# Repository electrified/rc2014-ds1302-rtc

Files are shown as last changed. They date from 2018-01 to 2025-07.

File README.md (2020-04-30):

# DS1302 Real Time Clock for the RC2014 computer

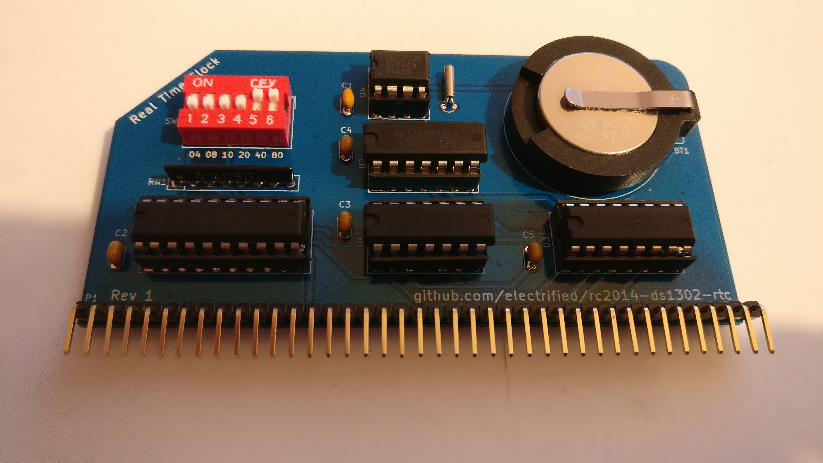
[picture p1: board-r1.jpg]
Picture of the board


## The board
RomWBW has code to support a DS1302 Real Time Clock, enabling files to be timestamped and other timekeeping operations. This board implements the clock in a standard way for the RC2014. 

The design is largely based on the clock implementation on the [RetroBrew Computers SBC V2](https://retrobrewcomputers.org/doku.php?id=boards:sbc:sbc_v2:start) and [Zeta SBC V2](http://www.malinov.com/Home/sergeys-projects/zeta-sbc-v2).

## What can you use this for?
Telling the time :)

## Getting started with RomWBW

Set ```DSRTCENABLE``` to true in the configuration and rebuild your ROM image.

On startup you will see the time shown.

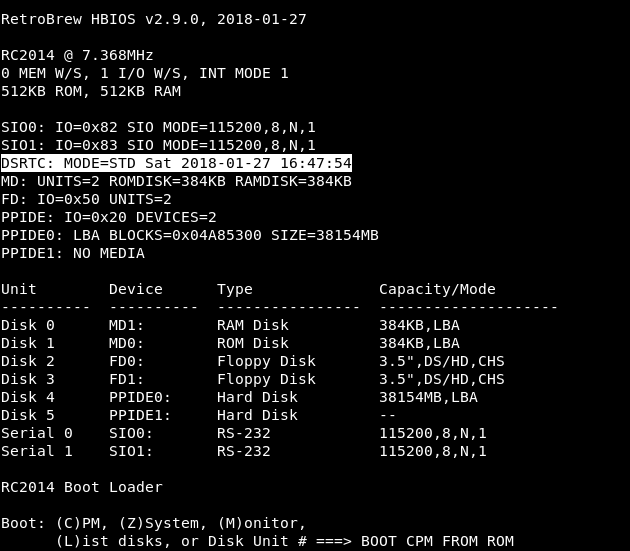
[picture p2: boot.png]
Boot


ZSystem has more complete support for time utilities than CP/M. After booting into ZSystem by pressing Z, Run ```ldds``` to load the resident time driver. ```td``` can then be used to set the time as well as view it.

In CP/M ```RTC.com``` can be used for querying and setting the clock but it is very basic.

## Jumpers
SW1 - Address configuration. For the default address of 0xC0, set switches 5 and 6 to on.

## Bill Of Materials

Reference| Value|Farnell part no|Rapid part no|Digi-key part no|
---------|------|---------------|-------------|----------------|
P1|1x39 right angled pin header|||732-5350-ND|
BT1|Keystone 106 20mm battery holder for CR2032|1650672||36-106-ND|
BT1|CR2032 battery|||P189-ND|
U1|CD74HCT688E COMPARATOR, SINGLE, PDIP-20|2407104||296-2131-5-ND|
U2|SN74HCT125N LOGIC, BUS BUFF TRI-ST QD, 14DIP|1739676||296-8386-5-ND|
U3|CD74HCT174E 74HCT CMOS, 74HCT174, DIP16, 5.5V|1105983||296-2100-5-ND|
U4|DS1302N+ RTC W/ RAM, 248B, D-D-M-Y, HH:MM:SS, DIP|2515367||DS1302N+-ND|
U5|SN74HCT32N IC, QUAD 2-INPUT OR, 74HCT32, DIP14|9591982||296-1615-5-ND|
C1-5|0.1uF MLCC capacitor|||BC2665CT-ND|
Y1|32.768 kHz crystal|9712887||535-9034-ND|
RN1|10k 8 Pin Commoned Resistor Network||63-0125|4608X-1-103LF-ND|
SW1|6 way DIL switch||80-0338|CT2066-ND|
U1|CONN IC DIP SOCKET 20POS TIN|||AE10015-ND|
U2|CONN IC DIP SOCKET 14POS TIN|||AE10012-ND|
U3|CONN IC DIP SOCKET 16POS TIN|||AE10013-ND|
U4|CONN IC DIP SOCKET 8POS TIN|||AE10011-ND|
U5|CONN IC DIP SOCKET 14POS TIN|||AE10012-ND|

## Construction tips
The footprint for the battery holder is designed for a Keystone 106, other battery holders should work if the pins are ~20.5mm apart, which seems to be fairly standard.

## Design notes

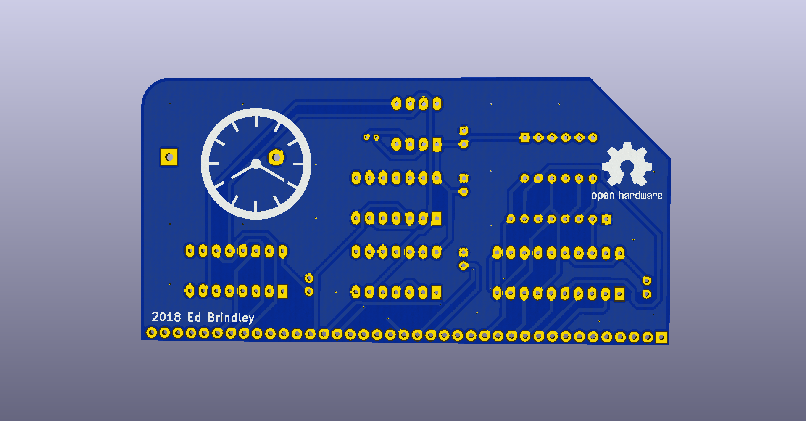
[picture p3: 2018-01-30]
rc2014-ds1302-rtc-back.png

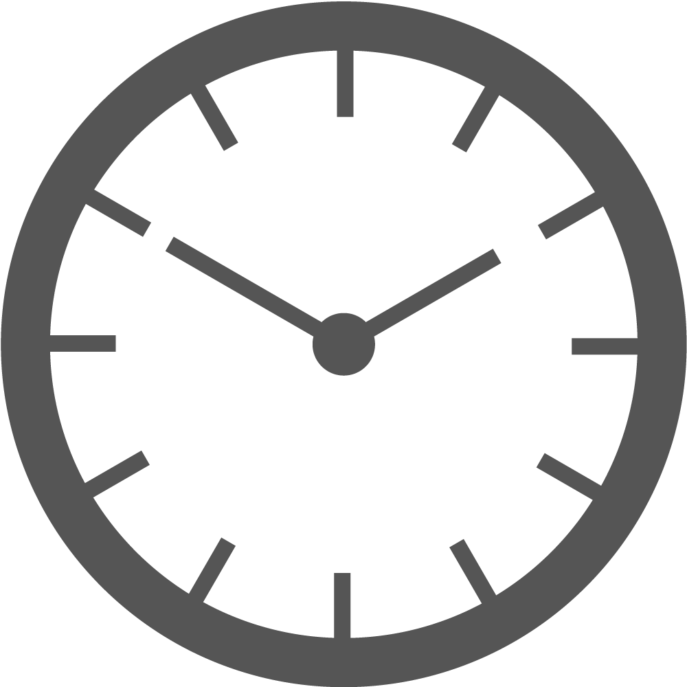
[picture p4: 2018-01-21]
clock.png

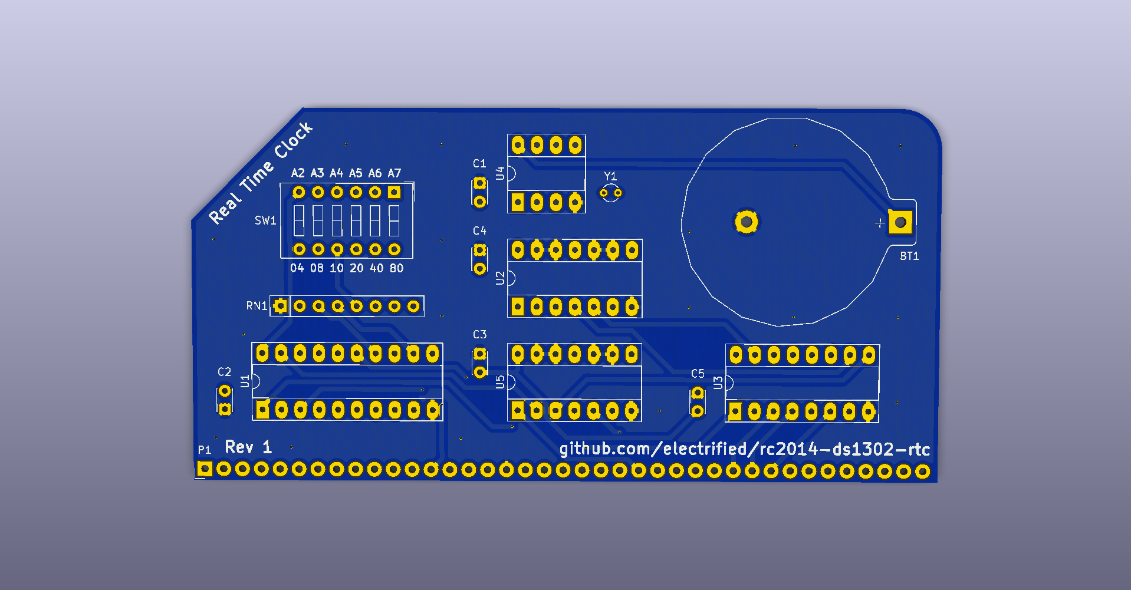
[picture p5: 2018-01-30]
rc2014-ds1302-rtc-front.png

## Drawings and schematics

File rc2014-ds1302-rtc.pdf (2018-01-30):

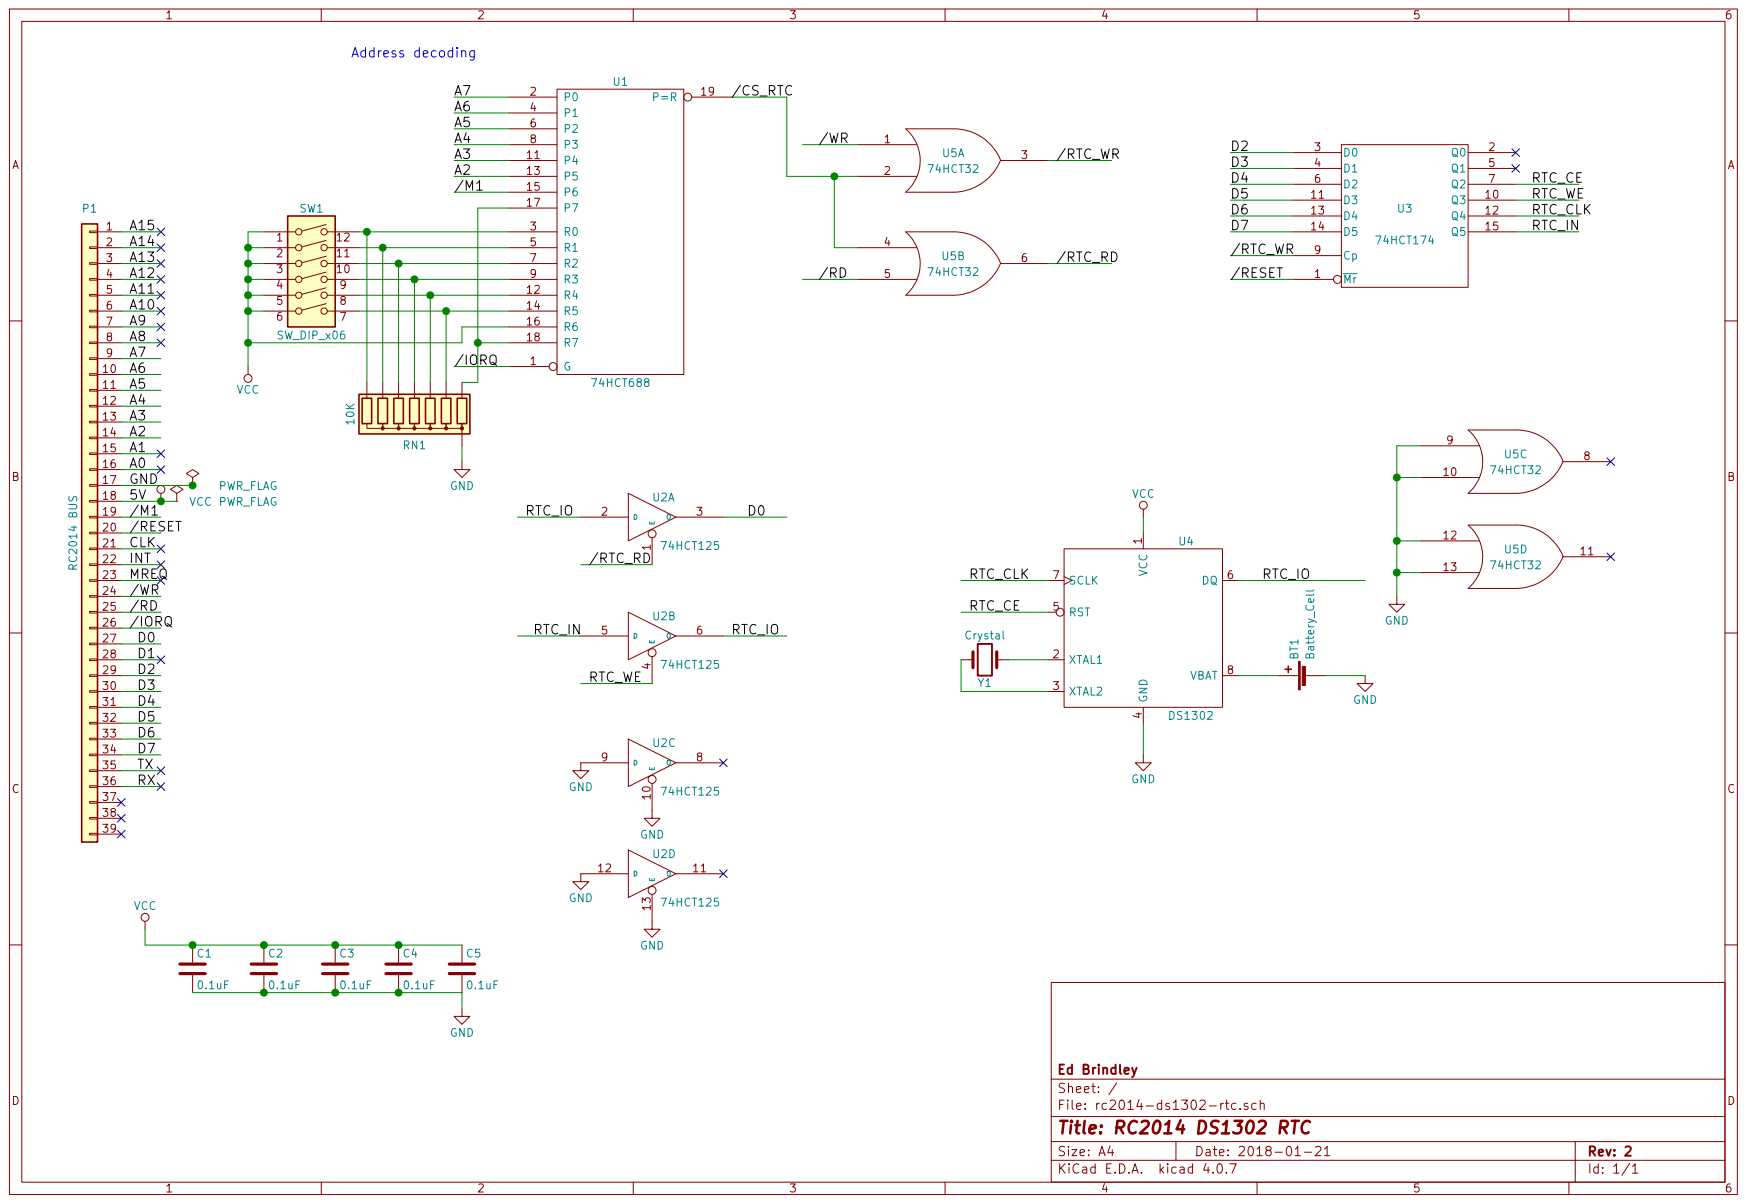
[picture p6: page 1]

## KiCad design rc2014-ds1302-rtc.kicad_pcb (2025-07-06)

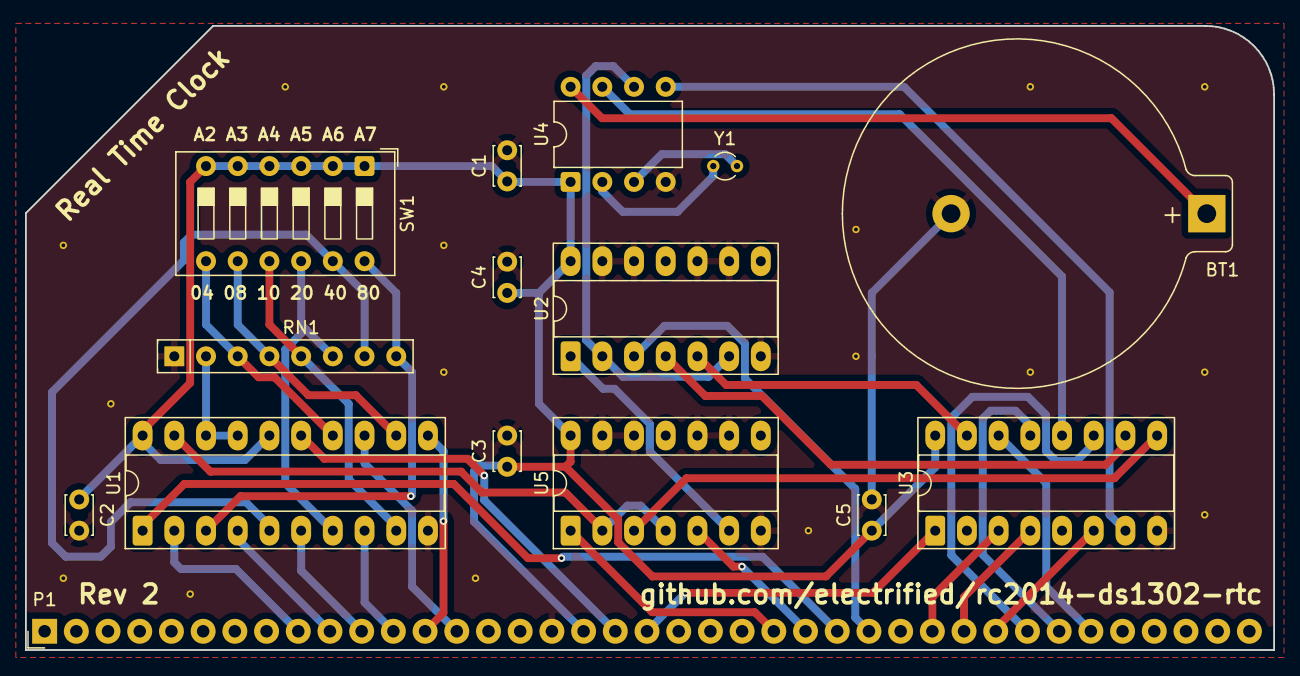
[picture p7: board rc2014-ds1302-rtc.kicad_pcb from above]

Board: 2 copper layers, 100.0 x 50.0 mm, 15 parts (0 on the bottom side), 38 nets.

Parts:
BT1: Battery_Cell; BatteryHolder_Keystone_106_1x20mm
C1, C2, C3, C4, C5: 0.1uF; C_Disc_D3.0mm_W2.0mm_P2.50mm
P1: RC2014 BUS; Pin_Header_Straight_1x39_Pitch2.54mm_NoSilk
RN1: 10K; R_Array_SIP8
SW1: SW_DIP_x06; SW_DIP_SPSTx06_Slide_9.78x17.42mm_W7.62mm_P2.54mm
U1: 74HCT688; DIP-20_W7.62mm_Socket_LongPads
U2: 74HCT125; DIP-14_W7.62mm_Socket_LongPads
U3: 74HCT174; DIP-16_W7.62mm_Socket_LongPads
U4: DS1302+; DIP-8_W7.62mm
U5: 74HCT32; DIP-14_W7.62mm_Socket_LongPads
Y1: Crystal; Crystal_Round_D2.0mm_Vertical

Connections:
/A2: P1.14, U1.13 (P5)
/A3: P1.13, U1.11 (P4)
/A4: P1.12, U1.8 (P3)
/A5: P1.11, U1.6 (P2)
/A6: P1.10, U1.4 (P1)
/A7: P1.9, U1.2 (P0)
/D0: P1.27, U2.3
/D2: P1.29, U3.3 (D0)
/D3: P1.30, U3.4 (D1)
/D4: P1.31, U3.6 (D2)
/D5: P1.32, U3.11 (D3)
/D6: P1.33, U3.13 (D4)
/D7: P1.34, U3.14 (D5)
/RTC_CE: U3.7 (Q2), U4.5 (CE)
/RTC_CLK: U3.12 (Q4), U4.7 (SCLK)
/RTC_IN: U2.5, U3.15 (Q5)
/RTC_IO: U2.2, U2.6, U4.6 (I/O)
/RTC_WE: U2.4, U3.10 (Q3)
//CS_RTC: U1.19 (P=R), U5.2, U5.4
//IORQ: P1.26, U1.1 (G)
//M1: P1.19, U1.15 (P6)
//RD: P1.25, U5.5
//RESET: P1.20, U3.1 (~Mr)
//RTC_RD: U2.1, U5.6
//RTC_WR: U3.9 (Cp), U5.3
//WR: P1.24, U5.1
GND: BT1.2 (-), C1.2, C2.2, C3.2, C4.2, C5.2, P1.17, RN1.1 (common), U1.10 (GND), U2.7 (GND), U2.9, U2.10, U2.12, U2.13, U3.8 (GND), U4.4 (GND), U5.7 (GND), U5.9, U5.10, U5.12, U5.13
unnamed: BT1.1 (+), U4.8 (VCC1)
unnamed: RN1.2 (R1), U1.17 (P7), U1.18 (R7)
unnamed: RN1.3 (R2), SW1.7, U1.14 (R5)
unnamed: RN1.4 (R3), SW1.8, U1.12 (R4)
unnamed: RN1.5 (R4), SW1.9, U1.9 (R3)
unnamed: RN1.6 (R5), SW1.10, U1.7 (R2)
unnamed: RN1.7 (R6), SW1.11, U1.5 (R1)
unnamed: RN1.8 (R7), SW1.12, U1.3 (R0)
unnamed: U4.2 (X1), Y1.1
unnamed: U4.3 (X2), Y1.2
VCC: C1.1, C2.1, C3.1, C4.1, C5.1, P1.18, SW1.1, SW1.2, SW1.3, SW1.4, SW1.5, SW1.6, U1.16 (R6), U1.20 (VCC), U2.14 (VCC), U3.16 (VCC), U4.1 (VCC2), U5.14 (VCC)

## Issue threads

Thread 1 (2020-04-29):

Missing attribution statement/link to N8VEM/Zeta SBC

skiselev, 2020-04-29:
The RTC implementation appears to be largely based on N8VEM/RetroBrew Computers and Zeta SBC.
Please add an attribution statement, for example "The design is based on RetroBrew Computers SBC and Zeta SBC"
And the links to these projects:
RetroBrew Computers SBC V2: https://retrobrewcomputers.org/doku.php?id=boards:sbc:sbc_v2:start
Zeta SBC V2: http://www.malinov.com/Home/sergeys-projects/zeta-sbc-v2

electrified, 2020-04-30:
Hi Sergey,

You are correct it was largely based on the Zeta 2 circuit. Apologies for not crediting your project, this was an oversight. I've added a statement to the first paragraph of the readme.

The IDE board which was also retrobrew inspired already has a similar statement: https://github.com/electrified/rc2014-82c55-ide

Many thanks for your work on these projects!

skiselev, 2020-04-30:
Thank you!

Closed 2020-04-30.

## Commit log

2018-01-03 start pcb layout
    [rc2014-ds1302-rtc.kicad_pcb, rc2014-ds1302-rtc.sch]
2018-01-04 after autoroute
    [rc2014-ds1302-rtc.dsn, rc2014-ds1302-rtc.kicad_pcb]
2018-01-21 Think this is ready for manufacturing...
    [rc2014-ds1302-rtc.kicad_pcb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]
2018-01-30 Add schematic pdf and renders of pcb
2022-03-09 Start kicad 6 migration
    [rc2014-ds1302-rtc.dsn, rc2014-ds1302-rtc.kicad_pcb, rc2014-ds1302-rtc.kicad_sch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]
2022-10-18 Complete kicad 6 migration
    [rc2014-ds1302-rtc.kicad_pcb, rc2014-ds1302-rtc.kicad_sch]
2024-06-28 Start kicad 8 migration
    [rc2014-ds1302-rtc.kicad_pcb, rc2014-ds1302-rtc.kicad_sch]
2025-07-06 some updates for kicad 9 - still quite a lot of DRC failures
    [rc2014-ds1302-rtc.kicad_pcb, rc2014-ds1302-rtc.kicad_sch]
